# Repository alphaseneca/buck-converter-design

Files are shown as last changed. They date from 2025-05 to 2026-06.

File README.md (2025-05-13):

# buck-converter-design

This project focuses on the design and implementation of a **synchronous buck converter**, aiming for improved efficiency and reduced output ripple suitable for sensitive applications. The key aspect of the design is the careful selection of the **buck converter IC**, which plays a pivotal role in defining the overall performance, efficiency, and practicality of the system. Given the wide variety of ICs available, the process required in-depth research, tradeoff analysis, and simulation to select the most appropriate component.

## Introduction

A **buck converter** is a widely used DC-DC converter topology known for its simplicity and efficiency in stepping down voltage levels. However, the performance of a buck converter heavily depends on the **IC selected**, which determines parameters like efficiency, output ripple, switching frequency, and current handling capability.

In the early stages of this project, I explored various commercially available buck converter ICs. I started by reviewing the datasheet of the **LM2596-5V**, a commonly found and affordable buck converter IC used in general-purpose circuits. However, during the datasheet study, I realized that the LM2596 operates in **non-synchronous mode**, which uses an external diode in the freewheeling phase. This leads to higher losses, especially at lower output voltages or higher currents. And is also expensive.

Further research introduced me to the **synchronous buck converter topology**, where the freewheeling diode is replaced by a low-side MOSFET. This approach significantly improves efficiency by reducing diode losses, making it suitable for modern, high-performance applications where efficiency and thermal management are critical.

To assist in the selection process, I utilized **Texas Instruments' WEBENCH Designer**, an online tool that helps engineers simulate and optimize power supply designs based on their requirements. Using this tool, I evaluated various TI synchronous buck converter ICs, comparing parameters like efficiency, output current capability, switching frequency, and thermal performance.

## Theoretical Background

A **synchronous buck converter** is a type of step-down converter that replaces the freewheeling diode with a **low-side MOSFET**. It operates with two MOSFETs (high-side and low-side) and a PWM controller that ensures precise switching and dead-time management.

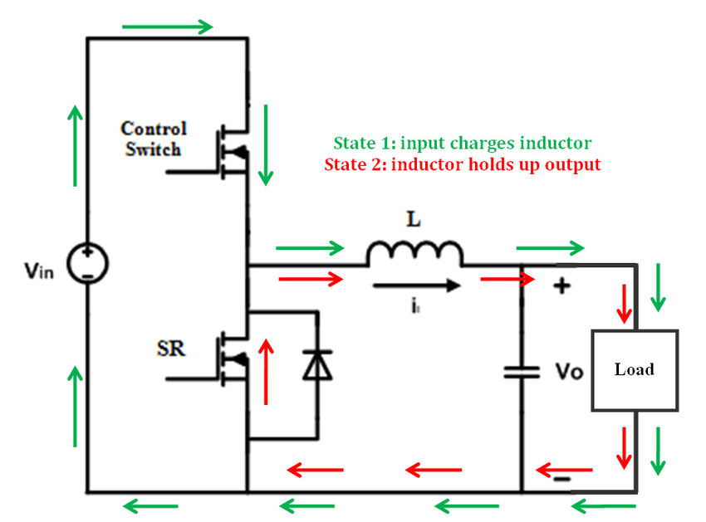
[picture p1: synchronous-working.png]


https://resources.pcb.cadence.com/blog/synchronous-vs-nonsynchronous-dc-dc-conversion

### How It Works:

- When the **high-side MOSFET** is ON, current flows from input → inductor → load → ground.
- When it's OFF, the **low-side MOSFET** turns ON and allows the inductor to continue supplying current (instead of using a diode).
- The **inductor** stores energy during the ON phase and releases it during the OFF phase, smoothing current.
- The **capacitor** filters voltage ripple and stabilizes output.

---

## Design Requirements

- Input Voltage Range: 10-14 VDC
- Output Voltage: 5V
- Output Continuous Current: 3A
- Switching Frequency: 600kHz
- Ripple Limits: \***\*2–3% of Vout i.e **0.02\*5 = 10mV\*\*
  [ Consumer / FCC Class B as per FCC Part 15 ]

### Components Selection

- Buck Converter IC:
  Used **TPS564257** because it supports a wide input range from 3V to 17V, which covers my system’s required 10V to 14V input. Its built-in enable threshold can be configured using external resistors to ensure the system only turns on when the input is above 10V, protecting against undervoltage. The converter also offers efficient performance at up to 4A output and includes safety features like overcurrent and thermal shutdown, making it a safe and compact solution for my power supply design.
- Inductor Value:
  Target inductor ripple current: **20% to 50% of output current (IOUT)**
  Use this to calculate **inductor value using the standard formula:**

$$
\Delta I_L = \frac{(V_{IN} - V_{OUT}) \times V_{OUT}}{V_{IN} \times L \times f_{SW}}
$$

$$
I_{L(PEAK)} = I_{OUT} + \frac{\Delta I_L}{2}
$$

And According to the datasheet the recommended Inductor Value is 4.7uH and calculating the current rating we came to know that the inductor should be able to handle around **4.2A.**

- Capacitor Value: The output capacitor value are also recommended in the datasheet as:
  $Cout$ ⇒ 44uF. And it should be able to handle the current as the following equation suggests and should have low ESR.
  And the input capacitor are $Cin$ = 10uF and an additional 100nF for high frequency filtering. And the Voltage rating should be greater than the Input Voltage range.

$$
I_{CO(RMS)} = \frac{V_{OUT} \times (V_{IN} - V_{OUT})}{\sqrt{12} \times V_{IN} \times L \times f_{SW}}
$$

### Output Voltage Calculation:

The output voltage is set by the help of voltage divider arrangement of the Rfbt and Rfbb resistors. The recommended Rfbt is 200kohm and Rfbb is 30kohm for setting the output to 5V. And for the voltage other than that we can set using this formula:

$$
V_{OUT} = 0.6V \times \left(1 + \frac{R_{FBT}}{R_{FBB}}\right)
$$

The datasheet recommends using 1% tolerance resistors and to improve efficiency at very light loads, consider using larger value resistors.

### UVLO (Under Voltage Lock Out)

The EN pin accepts the voltage from and using a series of resistors Rent and Renb the converter is only turned on when the input voltage is higher than 10V

**_Calculation for EN divider to turn ON at 10V:_**

$$
V_{EN} = V_{IN} \times \frac{RENB}{REN + RENB}
$$

$$
REN = RENB \times \left(\frac{V_{IN(ON)}}{V_{EN}} - 1\right)
$$

The $Ven$ is 1.19V and the $Renb$ should be in k ohm range and thus setting the $Renb$ ⇒ 30kohm will give $Ren$ ⇒ 210kohm.

### Reliability and Over Voltage Protection:

For adding the reliability of the buck converter and also to limit the upper voltage to around 14 V we added a TVS diode in parallel to to the input supply. The TVS diode is **PTVS12VZ1USK** to be exact.

### Circuit Design:

 
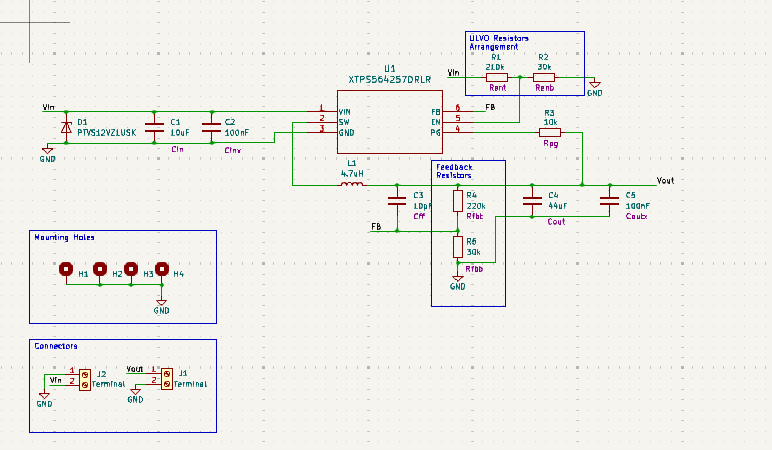
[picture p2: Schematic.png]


### PCB:

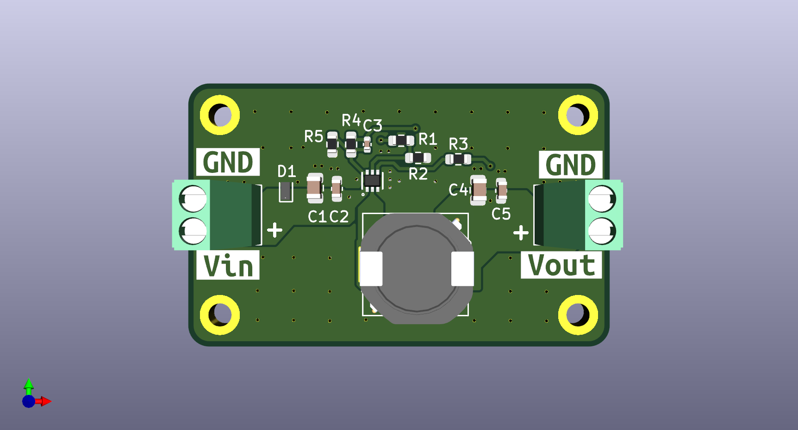
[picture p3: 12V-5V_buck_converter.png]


---

### Simulation:

Simulation of the circuit is done using **WEBENCH Power Designer**.

- [Startup Simulation](./Simulations/WBDesign_Startup-1.pdf)
- [Load Transient Simulation](./Simulations/WBDesign_Load%20Transient-2.pdf)
- [Input Transient Simulation](./Simulations/WBDesign_Input%20Transient-3.pdf)
- [Steady State Simulation](./Simulations/WBDesign_Steady%20State-4.pdf)

### References:

- [TI TPS564257 Buck Converter Datasheet](https://www.ti.com/lit/ds/symlink/tps564257.pdf)
- [WEBENCH Power Designer](https://webench.ti.com/power-designer/)

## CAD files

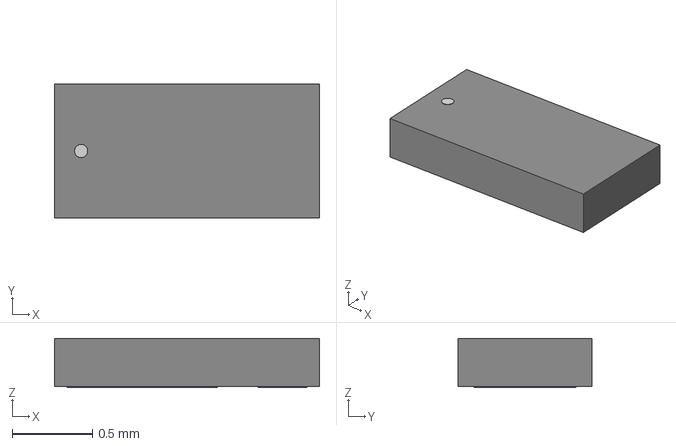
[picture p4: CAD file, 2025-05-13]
DSN1608-2_SOD964_NEX.step
1.65 x 0.838 x 0.307 mm

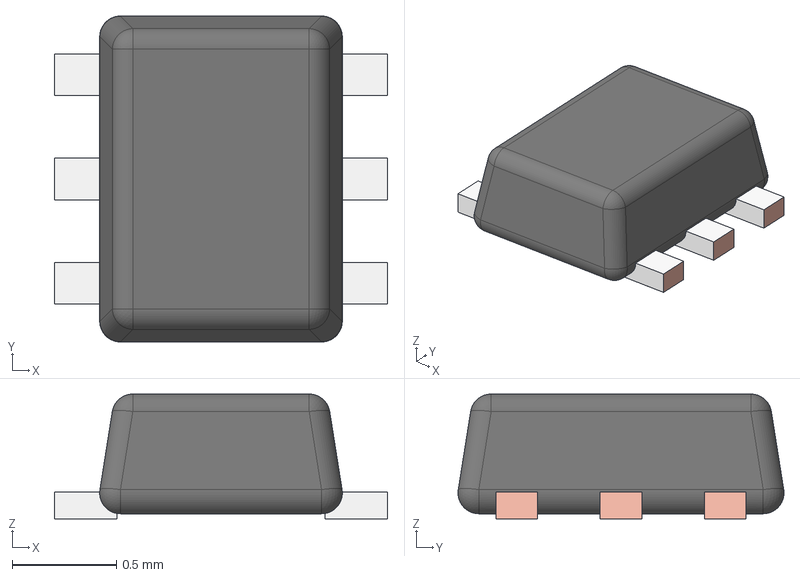
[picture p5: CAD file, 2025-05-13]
TPS564257DRLR/DRL0006A.stp
1.60 x 1.57 x 0.6 mm
FRAME-DRL0006A
BODY-SOT
PIN1-ID

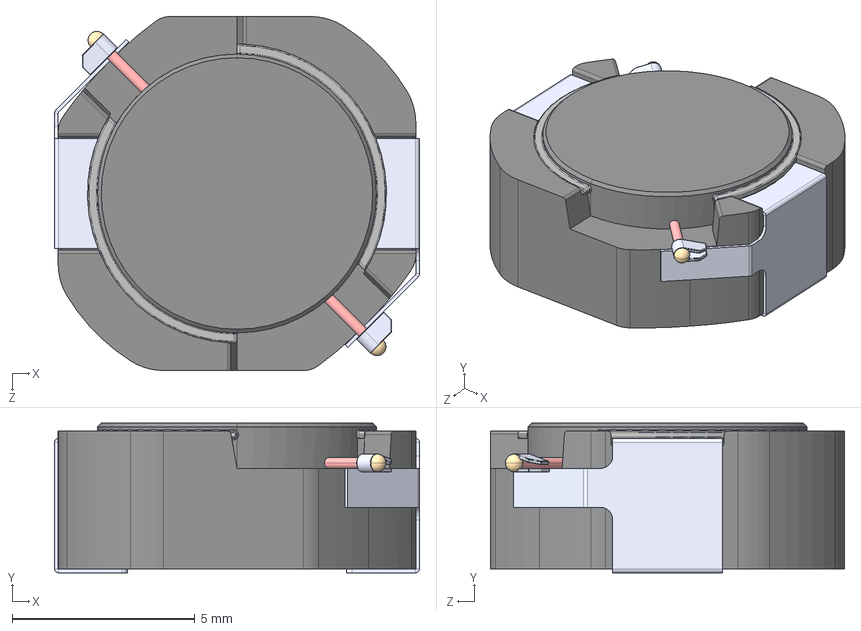
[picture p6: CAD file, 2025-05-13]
CLF10040T-4R7N-D/CLF10040T-4R7N-D.step
10.0 x 4.10 x 9.70 mm

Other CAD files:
TPS564257DRLR/DRL0006A.stl

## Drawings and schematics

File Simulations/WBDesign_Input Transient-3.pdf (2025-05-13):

## WEBENCH ® Design Report

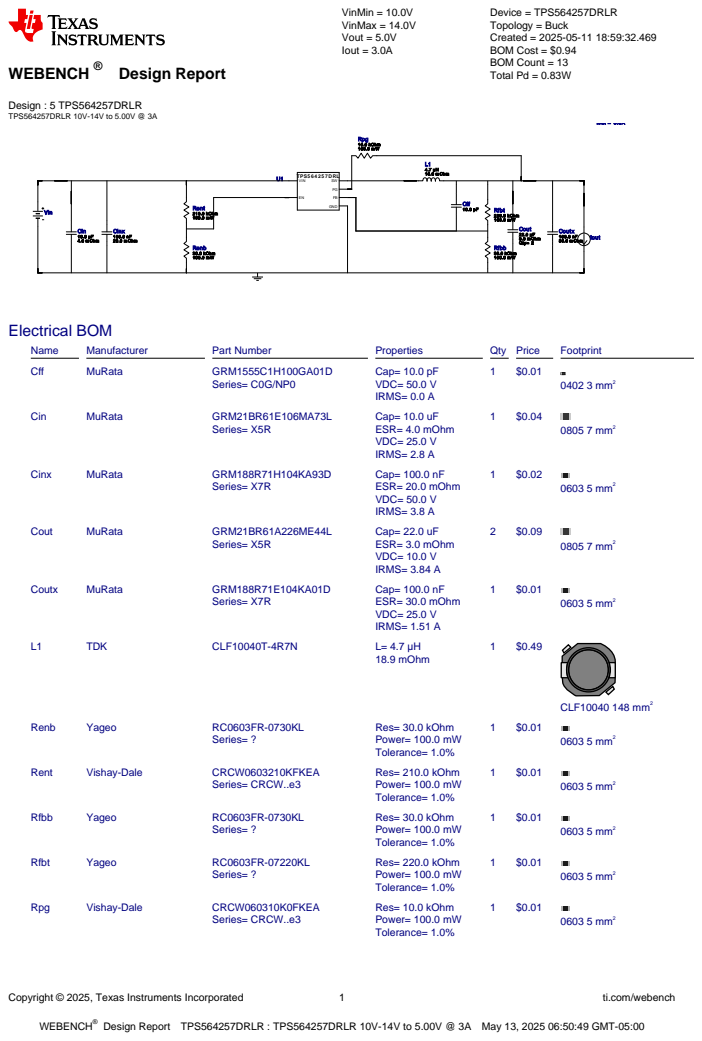
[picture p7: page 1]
Copyright © 2025, Texas Instruments Incorporated; ti.com/webench; WEBENCH®; Design : 5 TPS564257DRLR TPS564257DRLR 10V-14V to 5.00V @ 3A; VinMin = 10.0V VinMax = 14.0V Vout = 5.0V Iout = 3.0A; Device = TPS564257DRLR Topology = Buck Created = 2025-05-11 18:59:32.469 BOM Cost = $0.94 BOM Count = 13 Total Pd = 0.83W; Cff 10.0 pF; Coutx 100.0 nF 30.0 m Ohm; Cin 10.0 µF 4.0 m Ohm; Rpg 10.0 kOhm 100.0 m W; L1 4.7 µH 18.9 m Ohm; Cout 22.0 µF; 3.0 m Ohm Qty= 2; TPS5 6 4 2 5 7 DRL; VIN; GND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

Design Report TPS564257DRLR : TPS564257DRLR 10V-14V to 5.00V @ 3A May 13, 2025 06:50:49 GMT-05:00

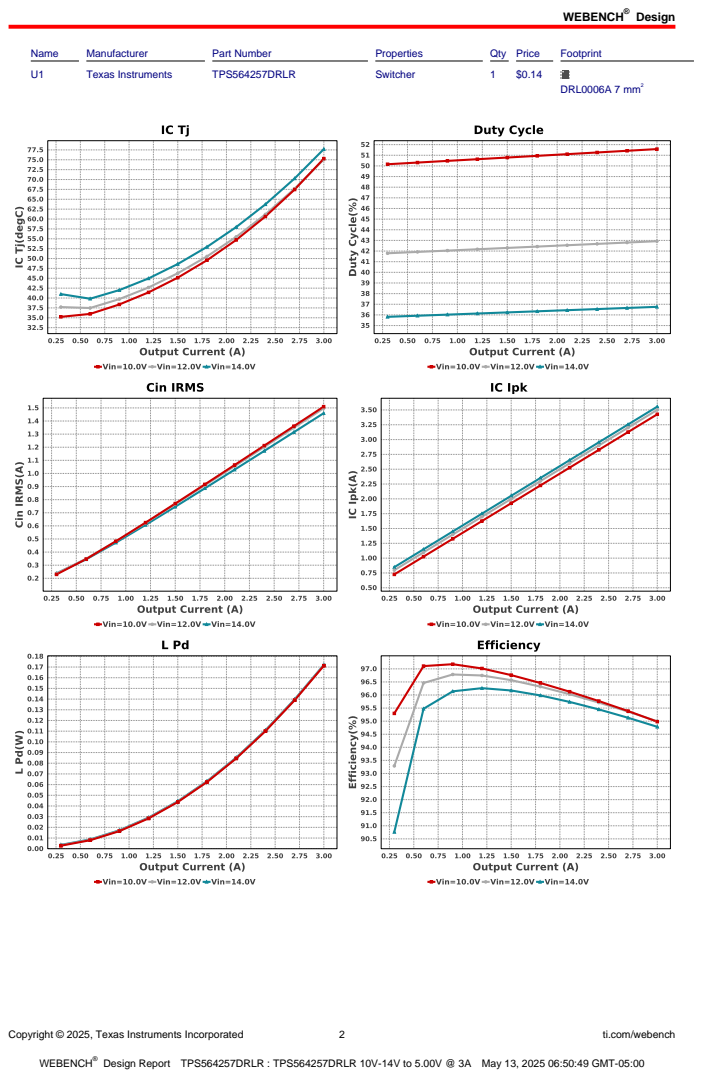
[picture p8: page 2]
Design; Copyright © 2025, Texas Instruments Incorporated; ti.com/webench; Name; Manufacturer; Part Number; Properties; Qty Price; Footprint; Texas Instruments; TPS564257DRLR; Switcher; DRL0006A 7 mm²

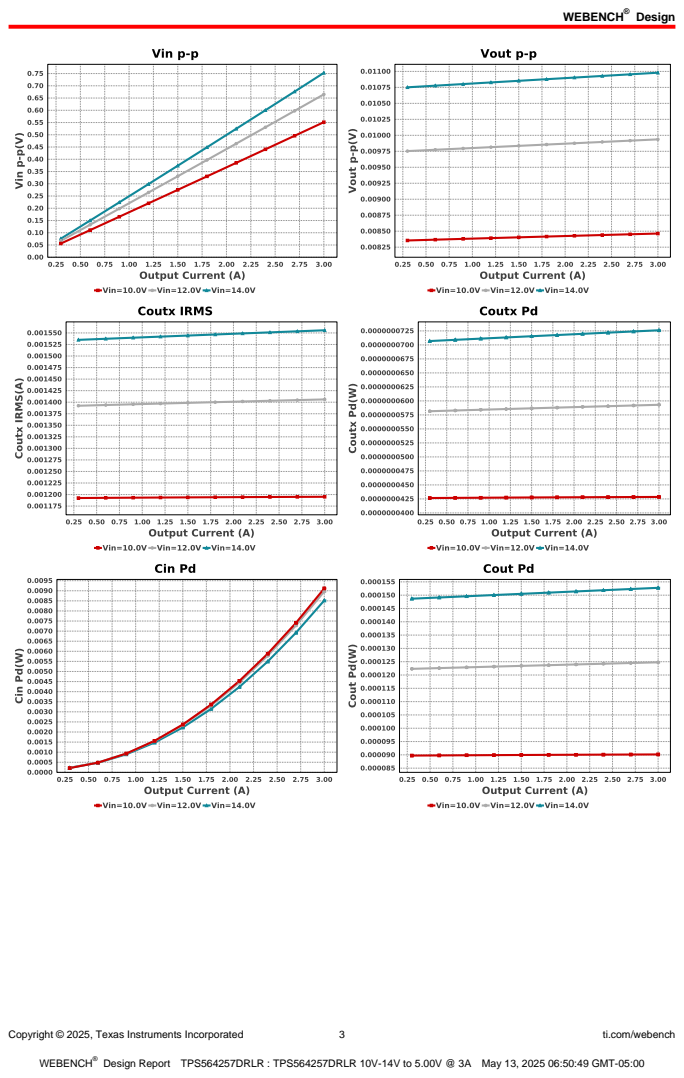
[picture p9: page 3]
Copyright © 2025, Texas Instruments Incorporated; ti.com/webench

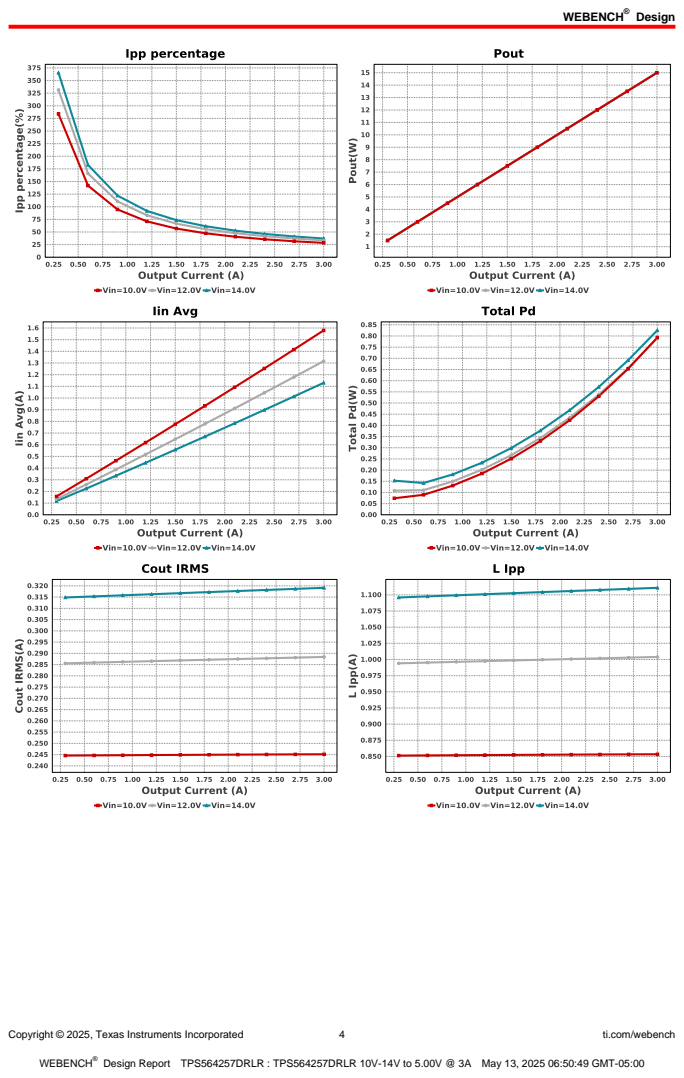
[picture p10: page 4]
Copyright © 2025, Texas Instruments Incorporated; ti.com/webench

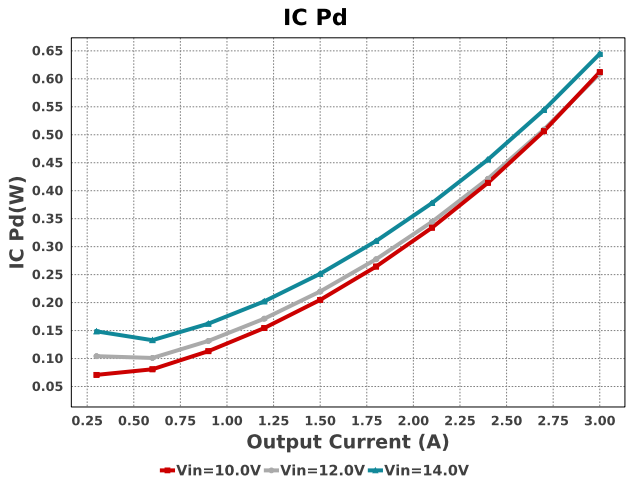
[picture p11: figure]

Copyright © 2025, Texas Instruments Incorporated | 5 | ti.com/webench

## Operating Values

# | Name | Value | Category | Description

1. BOM Count | 13 | Total Design BOM count
2. Total BOM | $0.94 | Total BOM Cost
3. Cin IRMS | 1.459 A | Capacitor | Input capacitor RMS ripple current
4. Cin Pd | 8.52 mW | Capacitor | Input capacitor power dissipation
5. Cout IRMS | 319.121 mA | Capacitor | Output capacitor RMS ripple current
6. Cout Pd | 152.76 µW | Capacitor | Output capacitor power dissipation
7. Coutx IRMS | 1.556 mA | Capacitor | Output capacitor_x RMS ripple current
8. Coutx Pd | 72.612 nW | Capacitor | Output capacitor_x power loss
9. IC Ipk | 3.555 A | IC | Peak switch current in IC
10. IC Pd | 644.63 mW | IC | IC power dissipation
11. IC Tj | 77.703 degC | IC | IC junction temperature
12. IC Tolerance | 6.0 mV | IC | IC Feedback Tolerance
13. ICThetaJA Effective | 74.0 degC/W | IC | IC junction-to-ambient thermal resistance with TI EVM
14. Iin Avg | 1.13 A | IC | Average input current
15. Ipp percentage | 37.029 % | Inductor | Inductor ripple current percentage (with respect to average inductor
| | | | current)
16. L Ipp | 1.111 A | Inductor | Peak-to-peak inductor ripple current
17. L Pd | 172.04 mW | Inductor | Inductor power dissipation
18. Cin Pd | 8.52 mW | Power | Input capacitor power dissipation
19. Cout Pd | 152.76 µW | Power | Output capacitor power dissipation
20. Coutx Pd | 72.612 nW | Power | Output capacitor_x power loss
21. IC Pd | 644.63 mW | Power | IC power dissipation
22. L Pd | 172.04 mW | Power | Inductor power dissipation
23. Total Pd | 825.463 mW | Power | Total Power Dissipation
24. Duty Cycle | 36.758 % | System
| | | Information | Duty cycle
25. Efficiency | 94.784 % | System
| | | Information | Steady state efficiency
26. FootPrint | 210.0 mm² | System
| | | Information | Total Foot Print Area of BOM components
27. Frequency | 619.766 kHz | System
| | | Information | Switching frequency
28. Iout | 3.0 A | System
| | | Information | Iout operating point
29. Mode | CCM | System
| | | Information | Conduction Mode
30. Pout | 15.0 W | System
| | | Information | Total output power
31. Vin | 14.0 V | System
| | | Information | Vin operating point
32. Vin p-p | 752.812 mV | System
| | | Information | Peak-to-peak input voltage
33. Vout | 5.0 V | System
| | | Information | Operational Output Voltage
34. Vout Actual | 5.0 V | System
| | | Information | Vout Actual calculated based on selected voltage divider resistors
35. Vout Tolerance | 2.796 % | System
| | | Information | Vout Tolerance based on IC Tolerance (no load) and voltage divider resistors if applicable
36. Vout p-p | 10.98 mV | System
| | | Information | Peak-to-peak output ripple voltage

Copyright © 2025, Texas Instruments Incorporated | 6 | ti.com/webench

## Design Inputs

Name | Value | Description
Iout | 3.0 | Maximum Output Current
VinMax | 14.0 | Maximum input voltage
VinMin | 10.0 | Minimum input voltage
Vout | 5.0 | Output Voltage
base_pn | TPS564257 | Base Product Number
source | DC | Input Source Type
Ta | 30.0 | Ambient temperature


Copyright © 2025, Texas Instruments Incorporated | 7 | ti.com/webench

## Assembly
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

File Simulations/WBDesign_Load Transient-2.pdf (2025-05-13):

## WEBENCH ® Design Report

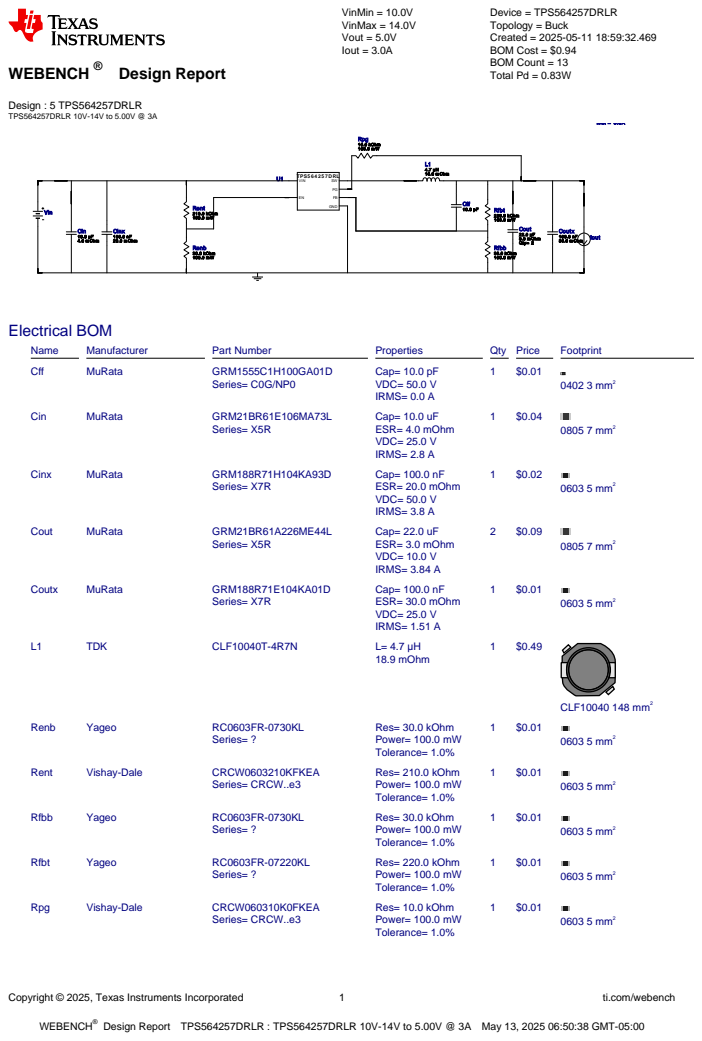
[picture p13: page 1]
Copyright © 2025, Texas Instruments Incorporated; ti.com/webench; WEBENCH®; Design : 5 TPS564257DRLR TPS564257DRLR 10V-14V to 5.00V @ 3A; VinMin = 10.0V VinMax = 14.0V Vout = 5.0V Iout = 3.0A; Device = TPS564257DRLR Topology = Buck Created = 2025-05-11 18:59:32.469 BOM Cost = $0.94 BOM Count = 13 Total Pd = 0.83W; Cff 10.0 pF; Coutx 100.0 nF 30.0 m Ohm; Cin 10.0 µF 4.0 m Ohm; Rpg 10.0 kOhm 100.0 m W; L1 4.7 µH 18.9 m Ohm; Cout 22.0 µF; 3.0 m Ohm Qty= 2; TPS5 6 4 2 5 7 DRL; VIN; GND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

Design Report TPS564257DRLR : TPS564257DRLR 10V-14V to 5.00V @ 3A May 13, 2025 06:50:38 GMT-05:00

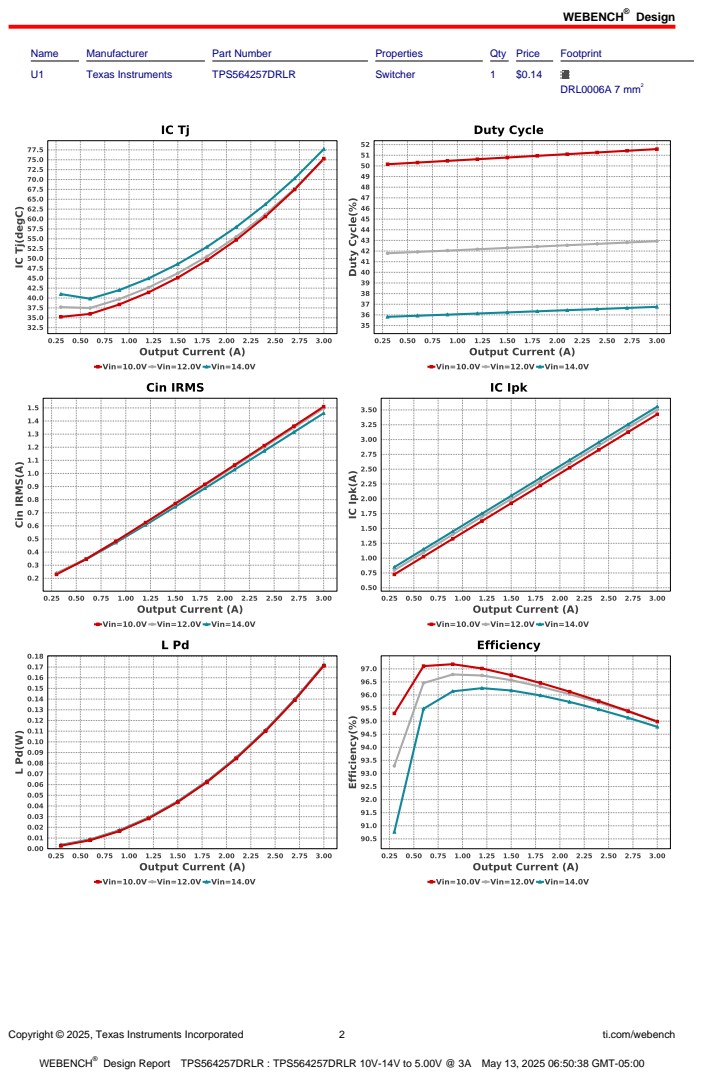
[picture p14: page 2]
Design; Copyright © 2025, Texas Instruments Incorporated; ti.com/webench; Name; Manufacturer; Part Number; Properties; Qty Price; Footprint; Texas Instruments; TPS564257DRLR; Switcher; DRL0006A 7 mm²

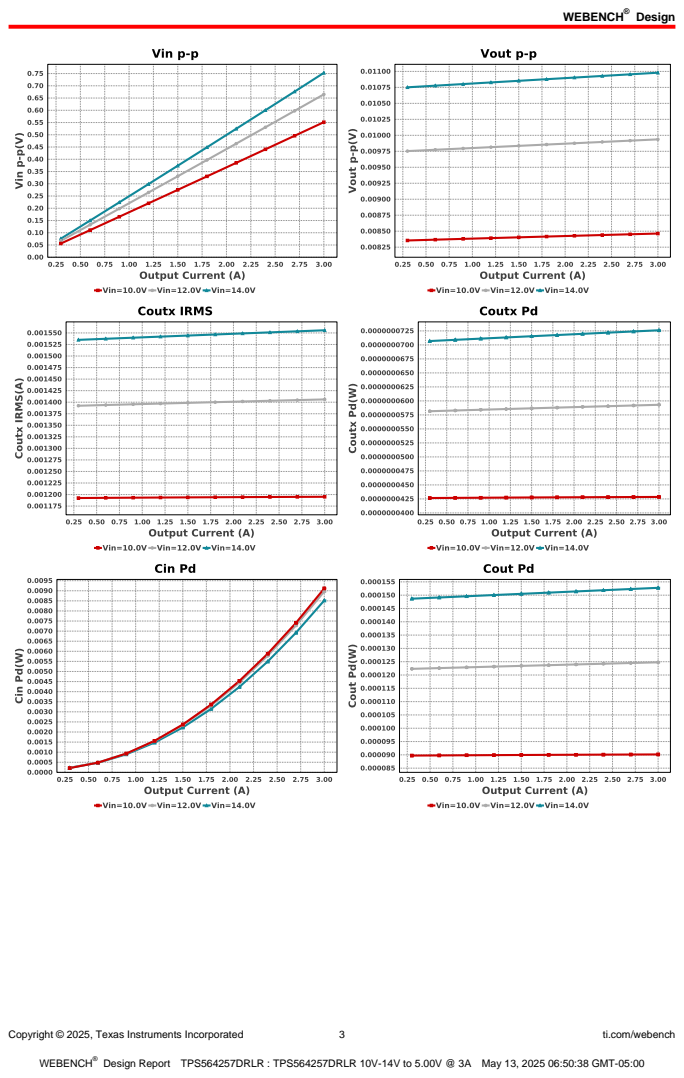
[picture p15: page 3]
Copyright © 2025, Texas Instruments Incorporated; ti.com/webench

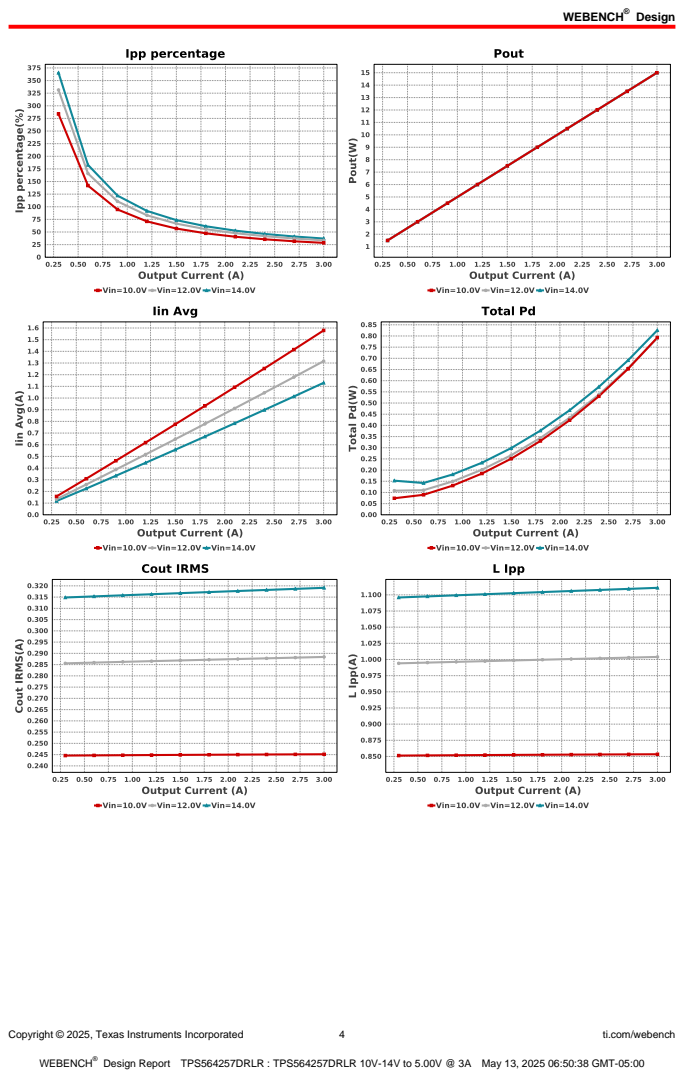
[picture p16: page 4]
Copyright © 2025, Texas Instruments Incorporated; ti.com/webench


Copyright © 2025, Texas Instruments Incorporated | 5 | ti.com/webench

## Operating Values

# | Name | Value | Category | Description

1. BOM Count | 13 | Total Design BOM count
2. Total BOM | $0.94 | Total BOM Cost
3. Cin IRMS | 1.459 A | Capacitor | Input capacitor RMS ripple current
4. Cin Pd | 8.52 mW | Capacitor | Input capacitor power dissipation
5. Cout IRMS | 319.121 mA | Capacitor | Output capacitor RMS ripple current
6. Cout Pd | 152.76 µW | Capacitor | Output capacitor power dissipation
7. Coutx IRMS | 1.556 mA | Capacitor | Output capacitor_x RMS ripple current
8. Coutx Pd | 72.612 nW | Capacitor | Output capacitor_x power loss
9. IC Ipk | 3.555 A | IC | Peak switch current in IC
10. IC Pd | 644.63 mW | IC | IC power dissipation
11. IC Tj | 77.703 degC | IC | IC junction temperature
12. IC Tolerance | 6.0 mV | IC | IC Feedback Tolerance
13. ICThetaJA Effective | 74.0 degC/W | IC | IC junction-to-ambient thermal resistance with TI EVM
14. Iin Avg | 1.13 A | IC | Average input current
15. Ipp percentage | 37.029 % | Inductor | Inductor ripple current percentage (with respect to average inductor
| | | | current)
16. L Ipp | 1.111 A | Inductor | Peak-to-peak inductor ripple current
17. L Pd | 172.04 mW | Inductor | Inductor power dissipation
18. Cin Pd | 8.52 mW | Power | Input capacitor power dissipation
19. Cout Pd | 152.76 µW | Power | Output capacitor power dissipation
20. Coutx Pd | 72.612 nW | Power | Output capacitor_x power loss
21. IC Pd | 644.63 mW | Power | IC power dissipation
22. L Pd | 172.04 mW | Power | Inductor power dissipation
23. Total Pd | 825.463 mW | Power | Total Power Dissipation
24. Duty Cycle | 36.758 % | System
| | | Information | Duty cycle
25. Efficiency | 94.784 % | System
| | | Information | Steady state efficiency
26. FootPrint | 210.0 mm² | System
| | | Information | Total Foot Print Area of BOM components
27. Frequency | 619.766 kHz | System
| | | Information | Switching frequency
28. Iout | 3.0 A | System
| | | Information | Iout operating point
29. Mode | CCM | System
| | | Information | Conduction Mode
30. Pout | 15.0 W | System
| | | Information | Total output power
31. Vin | 14.0 V | System
| | | Information | Vin operating point
32. Vin p-p | 752.812 mV | System
| | | Information | Peak-to-peak input voltage
33. Vout | 5.0 V | System
| | | Information | Operational Output Voltage
34. Vout Actual | 5.0 V | System
| | | Information | Vout Actual calculated based on selected voltage divider resistors
35. Vout Tolerance | 2.796 % | System
| | | Information | Vout Tolerance based on IC Tolerance (no load) and voltage divider resistors if applicable
36. Vout p-p | 10.98 mV | System
| | | Information | Peak-to-peak output ripple voltage

Copyright © 2025, Texas Instruments Incorporated | 6 | ti.com/webench

## Design Inputs

Name | Value | Description
Iout | 3.0 | Maximum Output Current
VinMax | 14.0 | Maximum input voltage
VinMin | 10.0 | Minimum input voltage
Vout | 5.0 | Output Voltage
base_pn | TPS564257 | Base Product Number
source | DC | Input Source Type
Ta | 30.0 | Ambient temperature


Copyright © 2025, Texas Instruments Incorporated | 7 | ti.com/webench

## Assembly
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

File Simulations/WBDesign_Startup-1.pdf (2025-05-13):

## WEBENCH ® Design Report

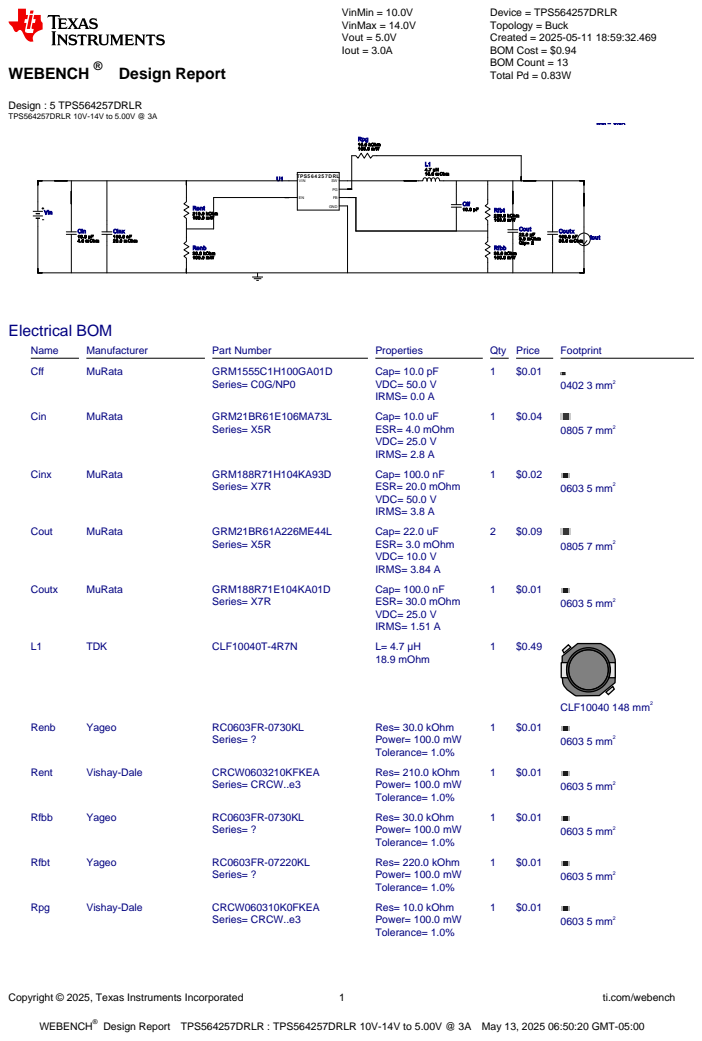
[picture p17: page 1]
Copyright © 2025, Texas Instruments Incorporated; ti.com/webench; WEBENCH®; Design : 5 TPS564257DRLR TPS564257DRLR 10V-14V to 5.00V @ 3A; VinMin = 10.0V VinMax = 14.0V Vout = 5.0V Iout = 3.0A; Device = TPS564257DRLR Topology = Buck Created = 2025-05-11 18:59:32.469 BOM Cost = $0.94 BOM Count = 13 Total Pd = 0.83W; Cff 10.0 pF; Coutx 100.0 nF 30.0 m Ohm; Cin 10.0 µF 4.0 m Ohm; Rpg 10.0 kOhm 100.0 m W; L1 4.7 µH 18.9 m Ohm; Cout 22.0 µF; 3.0 m Ohm Qty= 2; TPS5 6 4 2 5 7 DRL; VIN; GND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

Design Report TPS564257DRLR : TPS564257DRLR 10V-14V to 5.00V @ 3A May 13, 2025 06:50:20 GMT-05:00

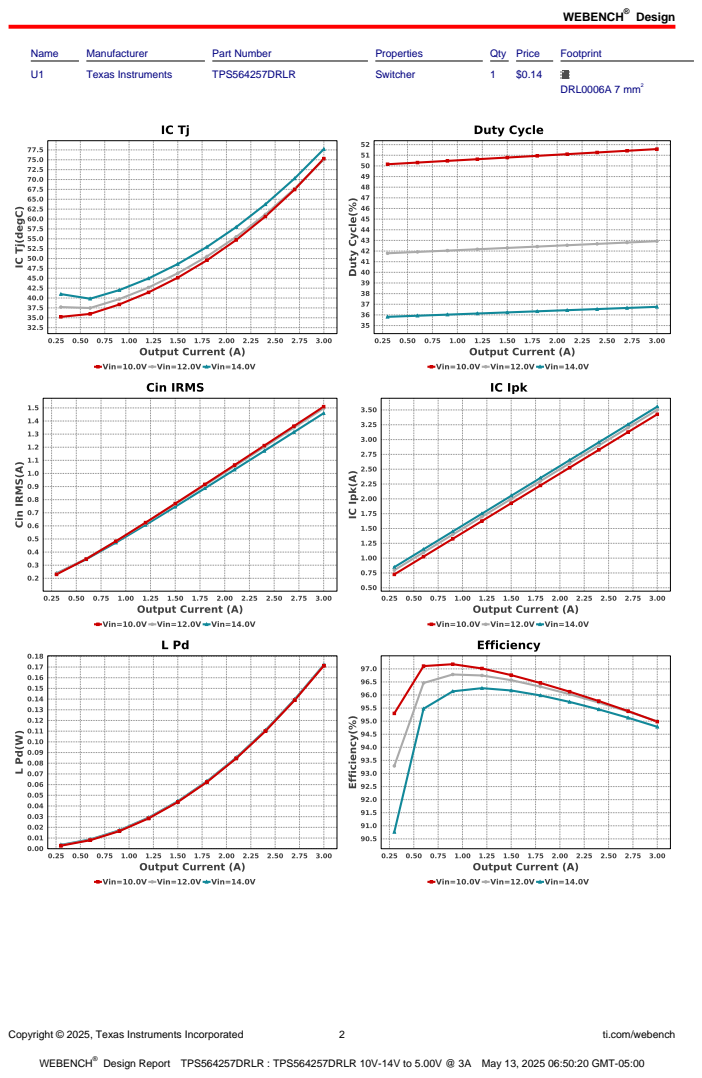
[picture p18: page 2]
Design; Copyright © 2025, Texas Instruments Incorporated; ti.com/webench; Name; Manufacturer; Part Number; Properties; Qty Price; Footprint; Texas Instruments; TPS564257DRLR; Switcher; DRL0006A 7 mm²

Copyright © 2025, Texas Instruments Incorporated; ti.com/webench

Copyright © 2025, Texas Instruments Incorporated; ti.com/webench


Copyright © 2025, Texas Instruments Incorporated | 5 | ti.com/webench

## Operating Values

# | Name | Value | Category | Description

1. BOM Count | 13 | Total Design BOM count
2. Total BOM | $0.94 | Total BOM Cost
3. Cin IRMS | 1.459 A | Capacitor | Input capacitor RMS ripple current
4. Cin Pd | 8.52 mW | Capacitor | Input capacitor power dissipation
5. Cout IRMS | 319.121 mA | Capacitor | Output capacitor RMS ripple current
6. Cout Pd | 152.76 µW | Capacitor | Output capacitor power dissipation
7. Coutx IRMS | 1.556 mA | Capacitor | Output capacitor_x RMS ripple current
8. Coutx Pd | 72.612 nW | Capacitor | Output capacitor_x power loss
9. IC Ipk | 3.555 A | IC | Peak switch current in IC
10. IC Pd | 644.63 mW | IC | IC power dissipation
11. IC Tj | 77.703 degC | IC | IC junction temperature
12. IC Tolerance | 6.0 mV | IC | IC Feedback Tolerance
13. ICThetaJA Effective | 74.0 degC/W | IC | IC junction-to-ambient thermal resistance with TI EVM
14. Iin Avg | 1.13 A | IC | Average input current
15. Ipp percentage | 37.029 % | Inductor | Inductor ripple current percentage (with respect to average inductor
| | | | current)
16. L Ipp | 1.111 A | Inductor | Peak-to-peak inductor ripple current
17. L Pd | 172.04 mW | Inductor | Inductor power dissipation
18. Cin Pd | 8.52 mW | Power | Input capacitor power dissipation
19. Cout Pd | 152.76 µW | Power | Output capacitor power dissipation
20. Coutx Pd | 72.612 nW | Power | Output capacitor_x power loss
21. IC Pd | 644.63 mW | Power | IC power dissipation
22. L Pd | 172.04 mW | Power | Inductor power dissipation
23. Total Pd | 825.463 mW | Power | Total Power Dissipation
24. Duty Cycle | 36.758 % | System
| | | Information | Duty cycle
25. Efficiency | 94.784 % | System
| | | Information | Steady state efficiency
26. FootPrint | 210.0 mm² | System
| | | Information | Total Foot Print Area of BOM components
27. Frequency | 619.766 kHz | System
| | | Information | Switching frequency
28. Iout | 3.0 A | System
| | | Information | Iout operating point
29. Mode | CCM | System
| | | Information | Conduction Mode
30. Pout | 15.0 W | System
| | | Information | Total output power
31. Vin | 14.0 V | System
| | | Information | Vin operating point
32. Vin p-p | 752.812 mV | System
| | | Information | Peak-to-peak input voltage
33. Vout | 5.0 V | System
| | | Information | Operational Output Voltage
34. Vout Actual | 5.0 V | System
| | | Information | Vout Actual calculated based on selected voltage divider resistors
35. Vout Tolerance | 2.796 % | System
| | | Information | Vout Tolerance based on IC Tolerance (no load) and voltage divider resistors if applicable
36. Vout p-p | 10.98 mV | System
| | | Information | Peak-to-peak output ripple voltage

Copyright © 2025, Texas Instruments Incorporated | 6 | ti.com/webench

## Design Inputs

Name | Value | Description
Iout | 3.0 | Maximum Output Current
VinMax | 14.0 | Maximum input voltage
VinMin | 10.0 | Minimum input voltage
Vout | 5.0 | Output Voltage
base_pn | TPS564257 | Base Product Number
source | DC | Input Source Type
Ta | 30.0 | Ambient temperature


Copyright © 2025, Texas Instruments Incorporated | 7 | ti.com/webench

## Assembly
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

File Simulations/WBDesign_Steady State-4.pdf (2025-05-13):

## WEBENCH ® Design Report

Copyright © 2025, Texas Instruments Incorporated; ti.com/webench; WEBENCH®; Design : 5 TPS564257DRLR TPS564257DRLR 10V-14V to 5.00V @ 3A; VinMin = 10.0V VinMax = 14.0V Vout = 5.0V Iout = 3.0A; Device = TPS564257DRLR Topology = Buck Created = 2025-05-11 18:59:32.469 BOM Cost = $0.94 BOM Count = 13 Total Pd = 0.83W; Cff 10.0 pF; Coutx 100.0 nF 30.0 m Ohm; Cin 10.0 µF 4.0 m Ohm; Rpg 10.0 kOhm 100.0 m W; L1 4.7 µH 18.9 m Ohm; Cout 22.0 µF; 3.0 m Ohm Qty= 2; TPS5 6 4 2 5 7 DRL; VIN; GND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

Design Report TPS564257DRLR : TPS564257DRLR 10V-14V to 5.00V @ 3A May 13, 2025 06:51:01 GMT-05:00

Design; Copyright © 2025, Texas Instruments Incorporated; ti.com/webench; Name; Manufacturer; Part Number; Properties; Qty Price; Footprint; Texas Instruments; TPS564257DRLR; Switcher; DRL0006A 7 mm²

Copyright © 2025, Texas Instruments Incorporated; ti.com/webench

Copyright © 2025, Texas Instruments Incorporated; ti.com/webench


Copyright © 2025, Texas Instruments Incorporated | 5 | ti.com/webench

## Operating Values

# | Name | Value | Category | Description

1. BOM Count | 13 | Total Design BOM count
2. Total BOM | $0.94 | Total BOM Cost
3. Cin IRMS | 1.459 A | Capacitor | Input capacitor RMS ripple current
4. Cin Pd | 8.52 mW | Capacitor | Input capacitor power dissipation
5. Cout IRMS | 319.121 mA | Capacitor | Output capacitor RMS ripple current
6. Cout Pd | 152.76 µW | Capacitor | Output capacitor power dissipation
7. Coutx IRMS | 1.556 mA | Capacitor | Output capacitor_x RMS ripple current
8. Coutx Pd | 72.612 nW | Capacitor | Output capacitor_x power loss
9. IC Ipk | 3.555 A | IC | Peak switch current in IC
10. IC Pd | 644.63 mW | IC | IC power dissipation
11. IC Tj | 77.703 degC | IC | IC junction temperature
12. IC Tolerance | 6.0 mV | IC | IC Feedback Tolerance
13. ICThetaJA Effective | 74.0 degC/W | IC | IC junction-to-ambient thermal resistance with TI EVM
14. Iin Avg | 1.13 A | IC | Average input current
15. Ipp percentage | 37.029 % | Inductor | Inductor ripple current percentage (with respect to average inductor
| | | | current)
16. L Ipp | 1.111 A | Inductor | Peak-to-peak inductor ripple current
17. L Pd | 172.04 mW | Inductor | Inductor power dissipation
18. Cin Pd | 8.52 mW | Power | Input capacitor power dissipation
19. Cout Pd | 152.76 µW | Power | Output capacitor power dissipation
20. Coutx Pd | 72.612 nW | Power | Output capacitor_x power loss
21. IC Pd | 644.63 mW | Power | IC power dissipation
22. L Pd | 172.04 mW | Power | Inductor power dissipation
23. Total Pd | 825.463 mW | Power | Total Power Dissipation
24. Duty Cycle | 36.758 % | System
| | | Information | Duty cycle
25. Efficiency | 94.784 % | System
| | | Information | Steady state efficiency
26. FootPrint | 210.0 mm² | System
| | | Information | Total Foot Print Area of BOM components
27. Frequency | 619.766 kHz | System
| | | Information | Switching frequency
28. Iout | 3.0 A | System
| | | Information | Iout operating point
29. Mode | CCM | System
| | | Information | Conduction Mode
30. Pout | 15.0 W | System
| | | Information | Total output power
31. Vin | 14.0 V | System
| | | Information | Vin operating point
32. Vin p-p | 752.812 mV | System
| | | Information | Peak-to-peak input voltage
33. Vout | 5.0 V | System
| | | Information | Operational Output Voltage
34. Vout Actual | 5.0 V | System
| | | Information | Vout Actual calculated based on selected voltage divider resistors
35. Vout Tolerance | 2.796 % | System
| | | Information | Vout Tolerance based on IC Tolerance (no load) and voltage divider resistors if applicable
36. Vout p-p | 10.98 mV | System
| | | Information | Peak-to-peak output ripple voltage

Copyright © 2025, Texas Instruments Incorporated | 6 | ti.com/webench

## Design Inputs

Name | Value | Description
Iout | 3.0 | Maximum Output Current
VinMax | 14.0 | Maximum input voltage
VinMin | 10.0 | Minimum input voltage
Vout | 5.0 | Output Voltage
base_pn | TPS564257 | Base Product Number
source | DC | Input Source Type
Ta | 30.0 | Ambient temperature


Copyright © 2025, Texas Instruments Incorporated | 7 | ti.com/webench

## Assembly
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

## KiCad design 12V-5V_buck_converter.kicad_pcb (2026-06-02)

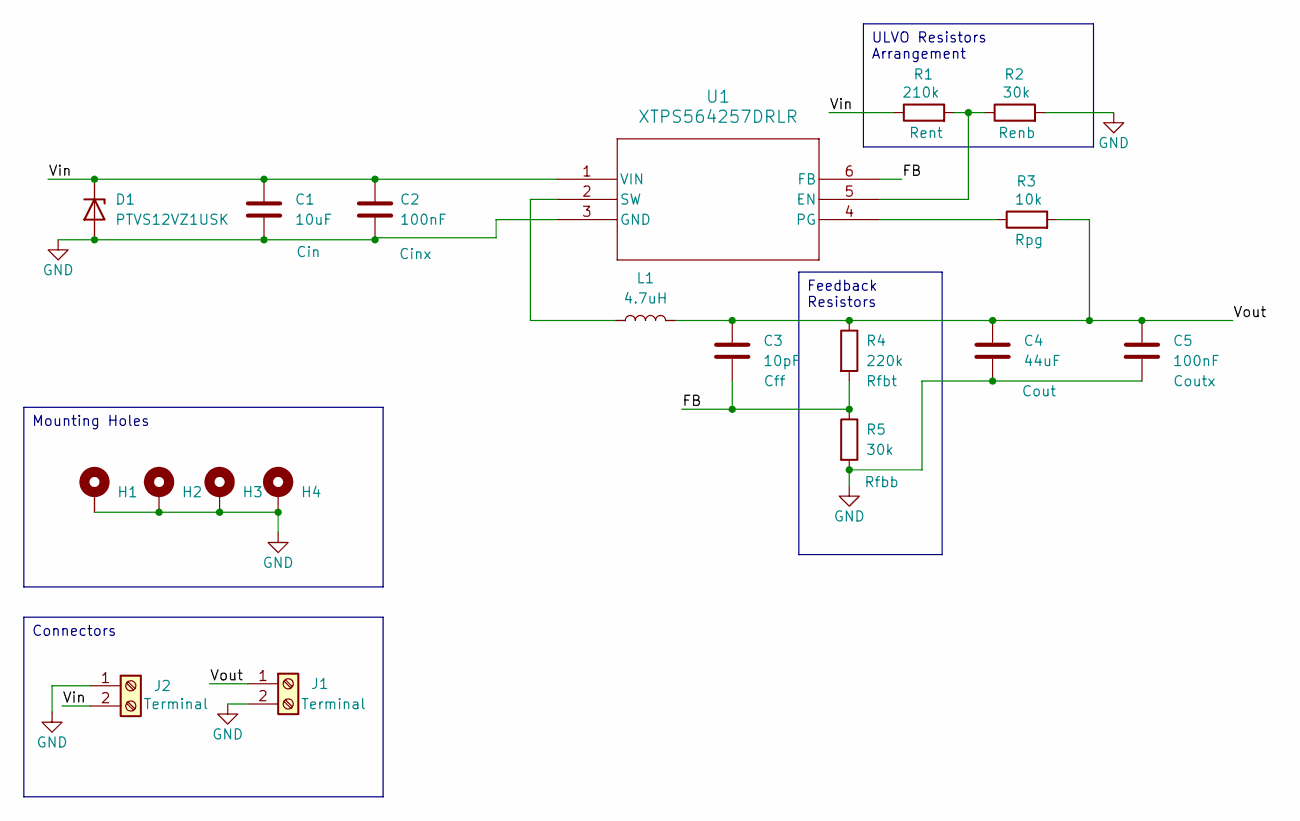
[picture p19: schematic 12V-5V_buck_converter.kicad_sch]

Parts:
C1: 10uF; C_0805_2012Metric
C2, C5: 100nF; C_0603_1608Metric
C3: 10pF; C_0402_1005Metric
C4: 44uF; C_0805_2012Metric
D1: PTVS12VZ1USK; Nexperia_DSN1608-2_1.6x0.8mm
H1, H2, H3, H4: MountingHole_Pad; MountingHole_2.2mm_M2_DIN965_Pad_TopBottom
J1, J2: Terminal; TerminalBlock_Phoenix_MPT-0,5-2-2.54_1x02_P2.54mm_Horizontal
L1: 4.7uH; IND_CLF10040T-4R7N-D
R1: 210k; R_0603_1608Metric
R2, R5: 30k; R_0603_1608Metric
R3: 10k; R_0603_1608Metric
R4: 220k; R_0603_1608Metric
U1: XTPS564257DRLR; TPS564242DRLR_TEX

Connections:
/FB: C3.2, R4.2, R5.1, U1.6 (FB)
/Vin: C1.1, C2.1, D1.1 (K), J2.2, R1.1, U1.1 (VIN)
/Vout: C3.1, C4.1, C5.1, J1.1, L1.2, R3.2, R4.1
GND: C1.2, C2.2, C4.2, C5.2, D1.2 (A), H1.1, H2.1, H3.1, H4.1, J1.2, J2.1, R2.2, R5.2, U1.3 (GND)
unnamed: R1.2, R2.1, U1.5 (EN)
unnamed: R3.1, U1.4 (PG)
unnamed: L1.1, U1.2 (SW)

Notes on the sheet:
Mounting Holes
Feedback Resistors
ULVO Resistors Arrangement
Connectors

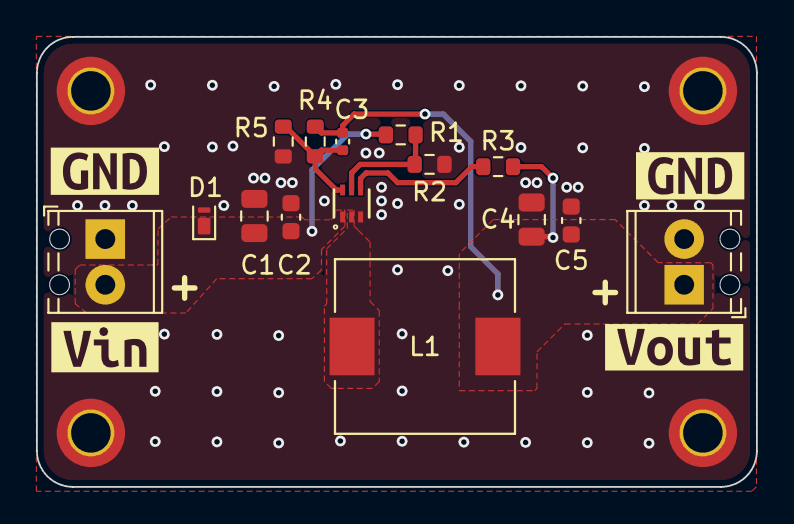
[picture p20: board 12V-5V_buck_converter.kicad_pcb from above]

Board: 2 copper layers, 40.0 x 25.0 mm, 23 parts (0 on the bottom side), 7 nets.

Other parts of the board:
kibuzzard-6822FF75: G***; kibuzzard-6822FF75
kibuzzard-6822FFBE: G***; kibuzzard-6822FFBE
kibuzzard-68230884, kibuzzard-68230884#2: G***; kibuzzard-68230884

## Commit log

2026-06-02 chore: added workflow release file
    [12V-5V_buck_converter.kicad_sch]
2026-06-02 fix: changed for KICAD 10
    [12V-5V_buck_converter.kicad_pcb]

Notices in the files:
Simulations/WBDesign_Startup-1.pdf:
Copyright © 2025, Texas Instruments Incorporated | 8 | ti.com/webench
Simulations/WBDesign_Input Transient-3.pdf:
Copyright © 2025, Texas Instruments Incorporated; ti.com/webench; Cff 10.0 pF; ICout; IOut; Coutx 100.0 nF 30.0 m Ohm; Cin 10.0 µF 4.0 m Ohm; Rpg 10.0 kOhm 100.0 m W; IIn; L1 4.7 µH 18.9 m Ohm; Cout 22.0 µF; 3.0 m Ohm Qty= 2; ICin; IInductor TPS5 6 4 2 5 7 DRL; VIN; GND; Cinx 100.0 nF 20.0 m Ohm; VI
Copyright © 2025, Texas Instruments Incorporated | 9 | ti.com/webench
